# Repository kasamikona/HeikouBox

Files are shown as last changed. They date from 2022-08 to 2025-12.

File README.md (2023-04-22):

# HeikouBox
A messy project towards running ["Parallelogram" demo by lft (Linus Åkesson).](https://www.linusakesson.net/scene/parallelogram/index.php)

It includes the following:
1. Open FPGA demo board designed from the ground up, as the original hardware is no longer available.
The quality is low and may require some hardware hacking skills, but mostly aimed at being plug-and-play.
Requires a Cyclone III FPGA chip, specifically EP3C25E144C8N. These are generally rare/expensive.
2. Firmware, scripts and an FPGA configuration working towards dumping the Parallelogram demo binary.
3. (Future plans) Software emulation to eliminate the need for practically unobtainable hardware,
rip the music in high quality, and facilitate possible demo modifications.

## I just want to run the demo!
First you need to build the hardware.
- Obtain the parts (good luck) and get boards made (designed to JLCPCB's requirements).
- At this stage the OLED & buttons are unused by the current firmware.
- The neopixels & PS/2 port are also unused and may be removed later, they're semi scrapped features.

Load the basic firmware (SingleBoot arduino sketch) on the Blue Pill.
I recommend getting a kit with a ST-Link adapter which makes this very easy.

Download the extender.rbf file from lft's blog page, put it on a FAT32-formatted microSD card and insert it.

Make sure you have a good stable 5V DC power source, things may freak out if the power is weak.
Recommended to use a 5V 1A/2A wall wart. Center positive because we're somewhat sane here.

Hook up the VGA and audio connections, power it on and wait a few seconds.
If you did everything right, the demo should run. Please enjoy.

## Terminology
I use the following terminology for this quite weird architecture:
- Core = the FPGA, or the daughter board holding it
- Hub = the STM32 Blue Pill microcontroller which loads a configuration into the core etc.
- Firmware = the program on the hub, currently an arduino sketch
- Configuration = a design project for the FPGA, or hardware-loadable files generated from it

## License
I haven't applied a proper license to the project yet, so the following applies:
- The Parallelogram demo and any material from it belongs to Linus Åkesson.
- Any other work here was created by me (kasamikona).
- Please don't take and claim it as your own or do anything else bad with it.
- Feel free to play around and modify it, but I won't accept pull requests.

## Acknowledgement
Thank you to Linus Åkesson for making such an interesting demo and inspiring this project.

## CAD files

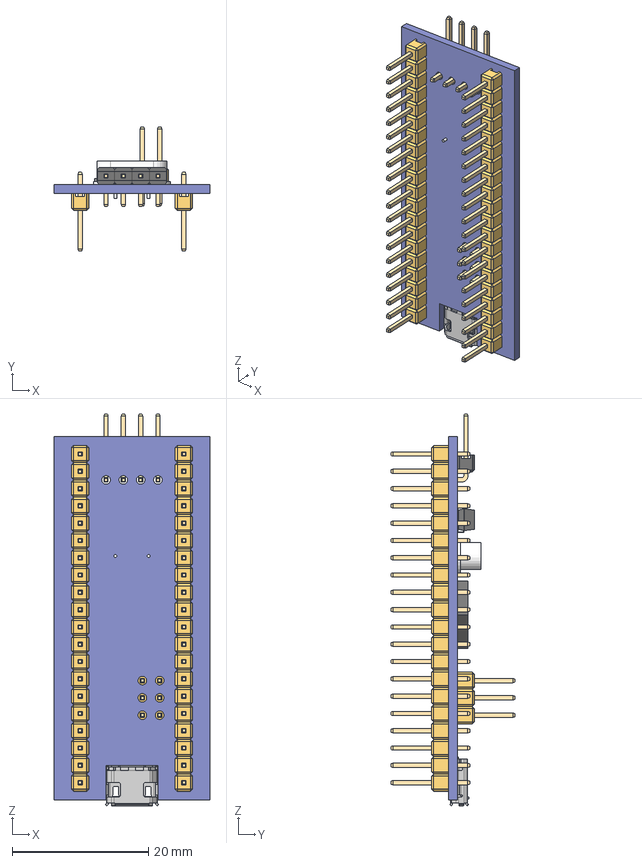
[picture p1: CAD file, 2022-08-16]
hardware/project_libraries/models/bluepill.step
22.9 x 18.3 x 57.6 mm
Oscillator_HC-49/S
STM32F103C8T6_BluePill_Board
Oscillator_MC-306
STM32_LQFP48
Tactile_SMD_5x5mm
Header_L4_10x4.8
Header_Male_2x3x11.6
Header_Male_1x20x11.6 x 2

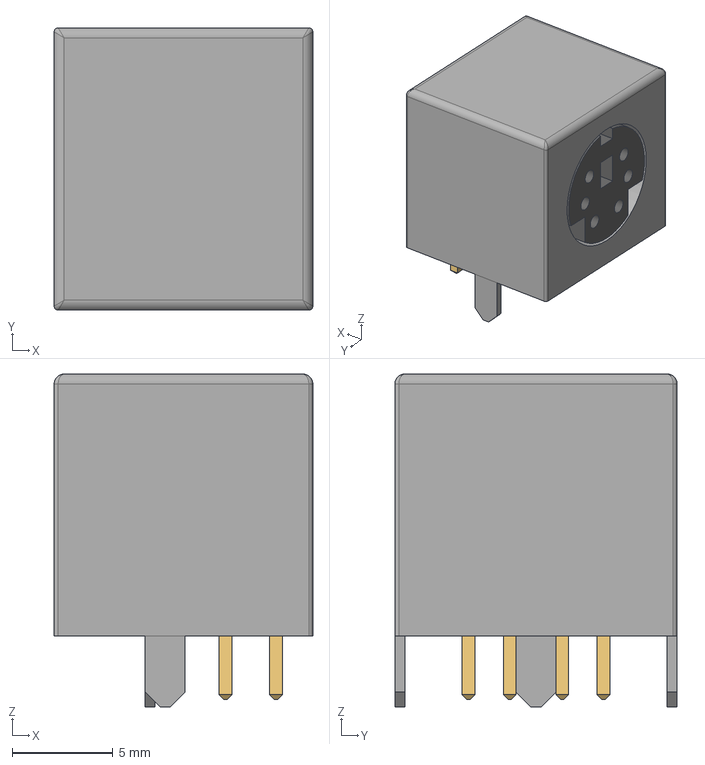
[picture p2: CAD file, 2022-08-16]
hardware/project_libraries/models/Mini-DIN-6P.step
12.8 x 14.0 x 16.5 mm

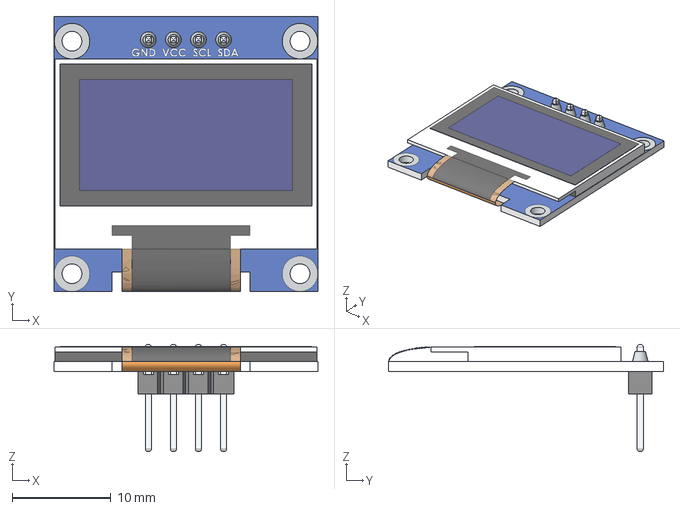
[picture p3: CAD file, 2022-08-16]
hardware/project_libraries/models/ssd1306.step
26.7 x 27.9 x 10.8 mm

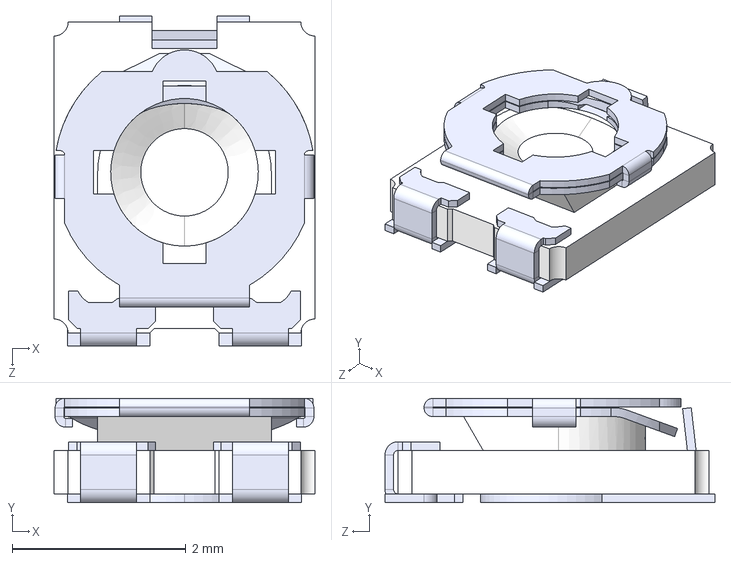
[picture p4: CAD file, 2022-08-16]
hardware/project_libraries/models/tc33x.step
3.00 x 1.20 x 3.80 mm

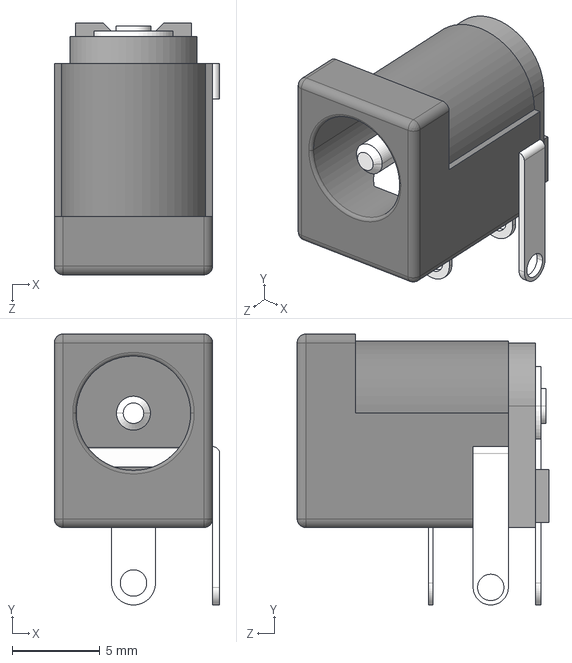
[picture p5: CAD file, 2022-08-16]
hardware/project_libraries/models/DC-Jack-2.1.step
9.40 x 15.4 x 14.3 mm

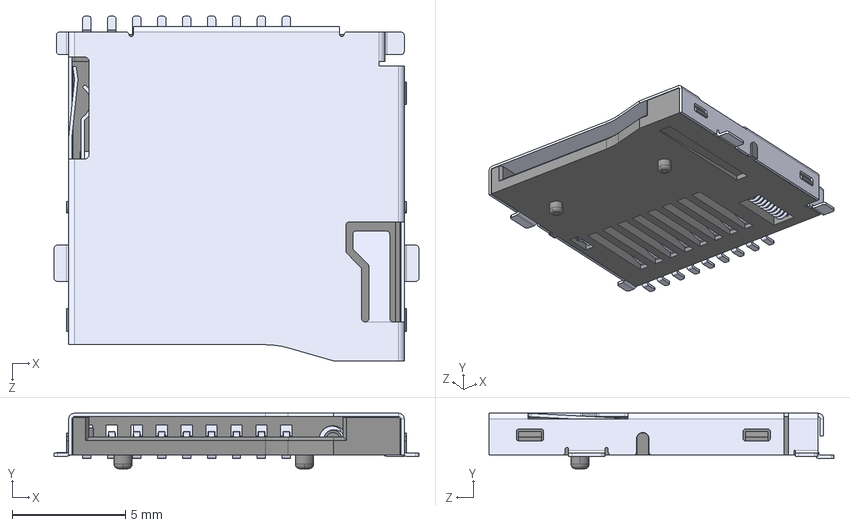
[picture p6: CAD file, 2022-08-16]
hardware/project_libraries/models/TF-01A.step
16.1 x 2.45 x 15.2 mm

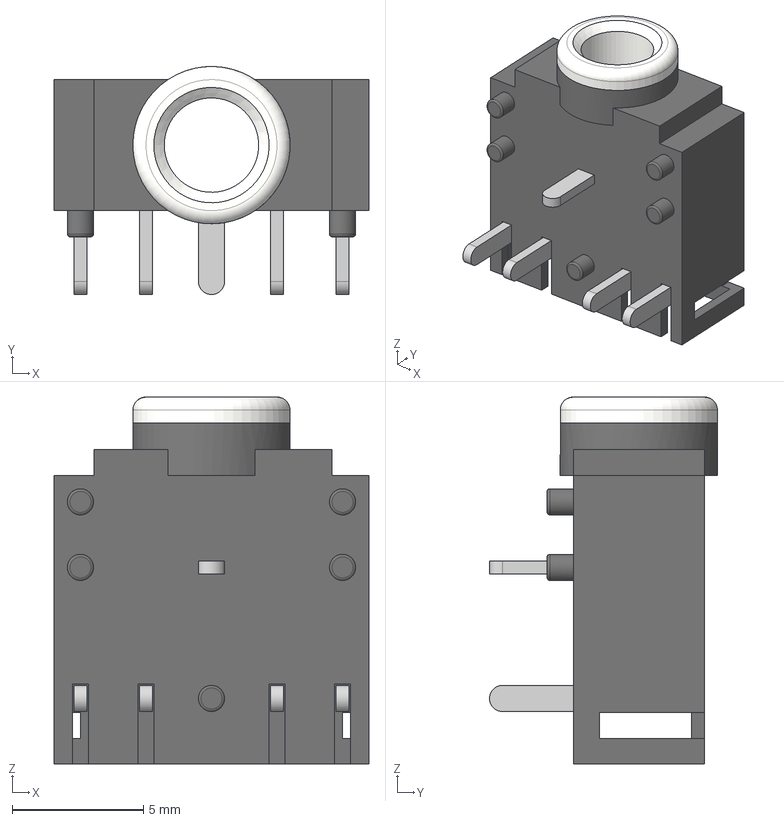
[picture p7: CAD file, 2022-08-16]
hardware/project_libraries/models/pj-307.step
12.0 x 8.70 x 14.0 mm

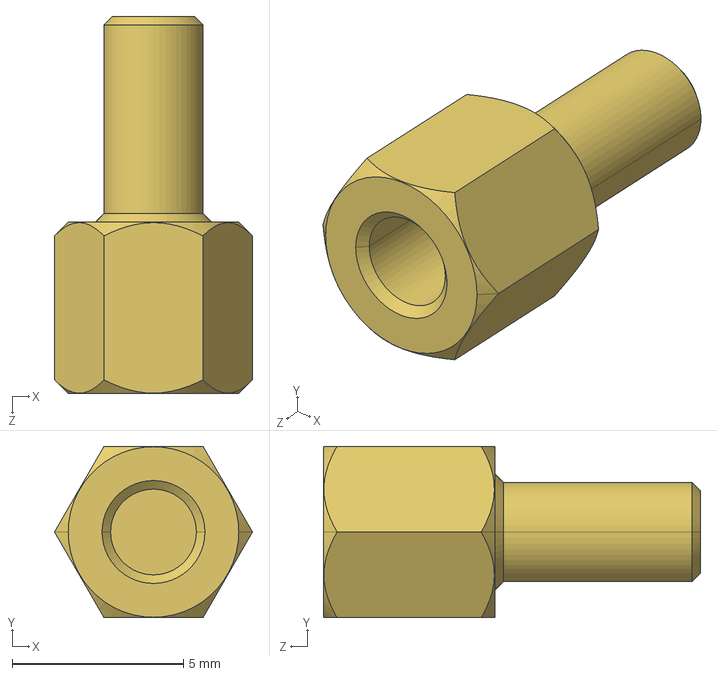
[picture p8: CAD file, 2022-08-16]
hardware/project_libraries/models/m3standoff5mm.step
5.77 x 5.00 x 11.0 mm

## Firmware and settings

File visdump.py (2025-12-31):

import struct, sys, os
from PIL import Image

DRAW_BIT_LAYERS = False
USE_NATIVE_COLOR = True
AUD_BOOST = 1
AUD_LIMIT = 32767//8
VIS_WIDTH = 512

def wordToColor(word):
	if USE_NATIVE_COLOR:
		# Interpret a0rrrr0gggg0bbbb (ignore a)
		#a=(word>>15)&1
		r=(word>>10)&15
		g=(word>>5)&15
		b=word&15
		# Convert to RGBA tuple
		return (r*17, g*17, b*17, 255)
	else:
		# Interpret irrrrrgggggbbbbb
		i=(word>>15)&1
		r=(word>>10)&31
		g=(word>>5)&31
		b=word&31
		r = r*2 + i
		g = g*2 + i
		b = b*2 + i
		return ((r<<2)+(r>>4), (g<<2)+(g>>4), (b<<2)+(b>>4), 255)

def bitToColor(word, bitpos):
	v = (word>>bitpos) & 1
	return (v*255, v*255, v*255, 255)

def main():
	if len(sys.argv) == 3 or len(sys.argv) == 4:
		inpath = sys.argv[1]
		outpath = sys.argv[2]
		if os.path.exists(outpath):
			print("Output filename already exists")
			return
		
		with open(sys.argv[1], "rb") as f:
			data = f.read()
		height = ((len(data)//2)+VIS_WIDTH-1)//VIS_WIDTH
		
		if DRAW_BIT_LAYERS:
			ofb, ofx = os.path.splitext(sys.argv[2])
			for bitpos in range(16):
				out = Image.new("RGBA", (VIS_WIDTH,height), (0,0,0,0))
				outpix = out.load()
				for addr in range(0,len(data),2):
					pixaddr = addr//2
					word = struct.unpack(">H", data[addr:addr+2])[0]
					outpix[pixaddr%VIS_WIDTH, pixaddr//VIS_WIDTH] = bitToColor(word, bitpos	)
				ofn = f"{ofb}_{bitpos:02d}{ofx}"
				out.save(ofn)
				print(f"Saved {len(data)//2} bits to {ofn} (bit position {bitpos})")
		else:
			out = Image.new("RGBA", (VIS_WIDTH,height), (0,0,0,0))
			outpix = out.load()
			for addr in range(0,len(data),2):
				pixaddr = addr//2
				word = struct.unpack(">H", data[addr:addr+2])[0]
				outpix[pixaddr%VIS_WIDTH, pixaddr//VIS_WIDTH] = wordToColor(word)
			out.save(sys.argv[2])
			print(f"Saved {len(data)//2} words to {sys.argv[2]}")
		
		if len(sys.argv) == 4:
			echopath = sys.argv[3]
			if os.path.exists(echopath):
				print("Echo buffer output filename already exists")
				return
			# Write WAV header
			datasize = 64*1024*2
			samplerate = 44100
			auddata = struct.pack("<4sI4s4sIHHIIHH4sI",
				b"RIFF",     # RIFF file chunk
				datasize+44, # ChunkSize = datasize + headersize
				b"WAVE",     # Format = wave file
				b"fmt ",     # Wave format chunk
				16,          # ChunkSize = 16
				1,           # AudioFormat = PCM
				2,           # NumChannels = Stereo
				44100,       # SampleRate = 44100Hz
				44100*4,     # ByteRate = SampleRate * 16bit * Stereo
				4,           # BlockAlign = 16bit * Stereo
				16,          # BitsPerSample = 16bit
				b"data",     # Audio data chunk
				datasize     # ChunkSize = datasize
			)
			# Write samples
			for y in range(256, 1280):
				for x in range(384, 448):
					# Read sample, boost/limit, and write out
					addr = ((y*512)+x)*2
					sample = struct.unpack(">h",data[addr:addr+2])[0]
					sample = min(max(-AUD_LIMIT, round(sample*AUD_BOOST)), AUD_LIMIT)
					auddata = auddata + struct.pack("<h",sample)
			with open(echopath, "wb") as audf:
				audf.write(auddata)
				print("Saved echo buffer to {0}".format(echopath))
	else:
		print(sys.argv[0], "<input.bin>", "<memory.png>", "[echo.wav]")

if __name__ == "__main__":
	main()

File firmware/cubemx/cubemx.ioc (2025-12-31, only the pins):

Mcu.UserName=STM32F103C8Tx
PA0-WKUP.GPIO_Label=NEOPIXEL
PA0-WKUP.Signal=GPIO_Output
PA1.GPIO_Label=KEYBOARD_DAT
PA1.Signal=GPIO_Input
PA10.GPIO_Label=MDB2_R
PA10.Signal=GPIO_Input
PA11.Signal=USB_DM
PA12.Signal=USB_DP
PA13.Signal=SYS_JTMS-SWDIO
PA14.Signal=SYS_JTCK-SWCLK
PA15.GPIO_Label=MDB3_R
PA15.Signal=GPIO_Input
PA2.GPIO_Label=KEYBOARD_CLK
PA2.Signal=GPIO_Input
PA3.GPIO_Label=CFG_NSTAT_R
PA3.Signal=GPIO_Input
PA4.GPIO_Label=SD_SS
PA4.Signal=SPI1_NSS
PA5.GPIO_Label=SD_SCK
PA5.Signal=SPI1_SCK
PA6.GPIO_Label=SD_MISO
PA6.Signal=SPI1_MISO
PA7.GPIO_Label=SD_MOSI
PA7.Signal=SPI1_MOSI
PA8.GPIO_Label=SD_DET
PA8.Signal=GPIO_Input
PA9.GPIO_Label=PWR_DET
PA9.Signal=GPIO_Analog
PB0.GPIO_Label=BUTTON_L
PB0.Signal=GPIO_Input
PB1.GPIO_Label=BUTTON_R
PB1.Signal=GPIO_Input
PB10.GPIO_Label=BUTTON_U
PB10.Signal=GPIO_Input
PB11.GPIO_Label=BUTTON_D
PB11.Signal=GPIO_Input
PB12.GPIO_Label=CFG_NCFG
PB12.Signal=GPIO_Output
PB13.GPIO_Label=CFG_DCLK
PB13.Signal=SPI2_SCK
PB14.Signal=SPI2_MISO
PB15.GPIO_Label=MDB4_CD_R
PB15.Signal=SPI2_MOSI
PB3.GPIO_Label=MDB5_R
PB3.Signal=GPIO_Input
PB4.GPIO_Label=MDB6_R
PB4.Signal=GPIO_Input
PB5.GPIO_Label=MDB7_R
PB5.Signal=GPIO_Input
PB6.GPIO_Label=MDB0_RX_R
PB6.Signal=USART1_TX
PB7.GPIO_Label=MDB1_TX_R
PB7.Signal=USART1_RX
PB8.GPIO_Label=OLED_SCL
PB8.Signal=I2C1_SCL
PB9.GPIO_Label=OLED_SDA
PB9.Signal=I2C1_SDA
PC13-TAMPER-RTC.GPIO_Label=ONBOARD_LED
PC13-TAMPER-RTC.Signal=GPIO_Output
PD0-OSC_IN.Signal=RCC_OSC_IN
PD1-OSC_OUT.Signal=RCC_OSC_OUT

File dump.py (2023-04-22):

import serial, struct, time, sys, os

def dump(ser, addr, count):
	request = struct.pack(">LH", addr&0xFFFFFF, count)[1:]

	#ser.reset_input_buffer()
	response = b''
	ser.write(request)
	while len(response) < (count*2+7):
		toread = (count*2+7)-len(response)
		if toread > 16:
			toread = 16
		newdata = ser.read(toread)
		response = response + newdata
		if len(newdata) == 0:
			print("Timed out")
			break
		time.sleep(0.01)
	#time.sleep(0.05)

	header = response[:5]
	checksum = response[-2:]
	response = response[5:-2]
	
	if header != request and False:
		print("Response header mismatch. Request/response:")
		print(request)
		print(header)
		return None
	
	if len(response) != count*2:
		print("Length mismatch. Expected {0}, got {1}.".format(count*2, len(response)))
		return response
	
	# TODO: checksum
	
	return response

if __name__ == "__main__":
	if len(sys.argv) == 3:
		ser = serial.Serial(sys.argv[1],timeout=2,baudrate=115200)
		try:
			with open(sys.argv[2], "wb") as dumpfile:
				for addr in range(0x000000, 0x0FFFFF, 4096):
					print("Read chunk {0:#08x}".format(addr))
					data = dump(ser, addr, 4096)
					if data == None:
						break
					dumpfile.write(data)
		except KeyboardInterrupt:
			pass
		ser.close()
	else:
		print(sys.argv[0], "<port>", "<output.bin>")

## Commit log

2020-08-21 Update to local libraries, minor work
    [FPGA_SUB_TQ144.sch, HeikouBox.sch, HeikouBoxCore.kicad_pcb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]
2020-08-22 Okay let's do this properly
    [HeikouBoxCore.kicad_pcb, HeikouBoxCore.sch]
2020-08-23 Match RAM signal lengths, fix connector alignment
    [HeikouBoxCore.kicad_pcb]
2020-08-24 Update hand-solder ground pad
    [HeikouBoxCore.kicad_pcb]
2020-08-24 Update 3D packages
    [HeikouBoxCore.kicad_pcb]
2020-08-24 Tidy traces a bit
    [HeikouBoxCore.kicad_pcb]
2020-08-24 Core: Update gerbers to V0.2
    [HeikouBoxCore-B.Cu.gbr, HeikouBoxCore-B.Mask.gbr, HeikouBoxCore-B.SilkS.gbr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]
2020-08-24 Core: Fix DRC errors and major short on power rail, redo gerbers
    [HeikouBoxCore-B_Cu.gbr, HeikouBoxCore-B_Mask.gbr, HeikouBoxCore-B_SilkS.gbr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]
2020-08-25 Core: Let's also make the gerbers properly, eh?
    [HeikouBoxCore-B_Cu.gbr, HeikouBoxCore-B_Mask.gbr, HeikouBoxCore-B_SilkS.gbr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]
2020-09-30 Fix invisible values?
    [HeikouBoxCore.sch]
2020-11-29 Core: Create/use overall footprint again
    [HeikouBox.sch, HeikouBoxCore.kicad_pcb, HeikouBoxCore.sch]
2021-03-13 Update components on core
    [HeikouBoxCore.kicad_pcb, HeikouBoxCore.sch]
2021-03-13 Initial mainboard v1.0 schematic finished
    [HeikouBox.sch]
2021-03-19 Tidy up and split to multi sheet
    [HeikouBox.kicad_pcb, HeikouBox.sch, part1-power.sch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]
2022-07-30 Replace MCU with blue pill, tidy up
    [HeikouBox.sch, part1-power.sch, part2-core.sch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]
2022-07-30 Fix DRC, make netlist
    [part1-power.sch, part2-core.sch, part3-av.sch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]
2022-07-31 Fix core
    [part1-power.sch]
2022-08-16 Mostly routed board
    [DC-Jack-2.1.step, HeikouBox.kicad_pcb, HeikouBox.sch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]
2022-08-17 Rerouted some logic
    [HeikouBox.kicad_pcb, part5-hub.sch]
2022-11-11 Mainboard v0.1 PCB ready for export
    [HeikouBox.kicad_pcb, HeikouBox.sch, part1-power.sch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]
2022-11-11 Move board near origin
    [HeikouBox.kicad_pcb]
2022-11-11 Generate gerbers for JLC
    [HeikouBox-B_Cu.gbr, HeikouBox-B_Mask.gbr, HeikouBox-B_SilkS.gbr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]
2022-11-11 Tidy up power nets
    [HeikouBox.kicad_pcb, HeikouBox.sch, part1-power.sch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]
2022-11-11 Update sheet version and date for v0.1
    [HeikouBox.kicad_pcb, HeikouBox.sch, part1-power.sch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]
2022-11-24 Fix dumb routing around JTAG
    [HeikouBox.kicad_pcb]
2022-11-24 Run 1.2v vreg from 3.3v to spread power
    [HeikouBox.kicad_pcb, part1-power.sch]
2022-11-24 Add 1ohm series resistors to regulator output caps
    [HeikouBox.kicad_pcb, part1-power.sch]
2022-11-25 Cleanup, add regulator input caps
    [HeikouBox.kicad_pcb, part1-power.sch]
2022-11-25 Cleanup, add rounded corners, bigger diode
    [HeikouBox.kicad_pcb, part1-power.sch]
2022-11-26 More tidy up, move vias
    [HeikouBox.kicad_pcb, HeikouBox.sch, part1-power.sch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]
2022-11-26 Fix bluepill position, routing cleanup
    [HeikouBox.kicad_pcb]
2022-11-27 Remove ambiguous core footprint markers
2022-11-27 Fix core orientation
    [HeikouBoxCore.kicad_pcb]
2022-11-27 Cleanup, change silkscreen reference size
    [HeikouBox.kicad_pcb]
2022-11-29 I'm da giant cap that takes all of the space (smaller caps)
    [HeikouBox.kicad_pcb, part1-power.sch, part2-core.sch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]
2022-12-02 BOM reduction
    [HeikouBox.kicad_pcb, part1-power.sch, part3-av.sch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]
2022-12-03 Shrink VGA ladders to make space for xbus redo
    [HeikouBox.kicad_pcb, part2-core.sch, part5-hub.sch]
2023-03-25 Update files
    [HeikouBox.kicad_pcb]
2023-03-26 Update regulator capacitor values
    [HeikouBox.kicad_pcb, part1-power.sch]
2023-03-27 Add VGA sync invert jumpers
    [HeikouBox.kicad_pcb, part3-av.sch]
2023-03-27 Remove these dumb mounting holes for core
    [HeikouBox.kicad_pcb, part1-power.sch]
2023-04-03 Cleanup routing
    [HeikouBox.kicad_pcb, part3-av.sch]
2023-04-04 Routing cleanup, rearrange neopixels again... Do I really need these?
    [HeikouBox.kicad_pcb]
2023-04-13 Fix SPI setup, apparently used transaction API entirely wrong.
    [SingleBoot.ino]
2023-05-04 Connect UART correctly, remove unused mdb connection & mdb terminology
    [HeikouBox.kicad_pcb, HeikouBox.sch, part2-core.sch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]
2023-05-05 Tidy PCB a bit
    [HeikouBox.kicad_pcb]
2025-12-31 Upload latest files
    [HeikouBox.kicad_pcb, HeikouBox.kicad_sch, part1-power.kicad_sch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]
